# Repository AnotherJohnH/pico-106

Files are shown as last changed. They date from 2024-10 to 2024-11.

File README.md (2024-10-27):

# pico-106

pico-106

Hybrid synthesizer inspired by the Roland Juno-106 (and close relatives).

Some DCOs driven by a Raspberry Pi Pico with a USB MIDI interface.

## Status

Usable as a musical instrument but plenty more to explore...
+ No LFO
+ No PWM, sub-oscillatgor or noise
+ No filter or VCA-envelope on the oscillator signal path

## Hardware

[schematic](https://github.com/AnotherJohnH/pico-106/blob/main/docs/schematic_v0.01.pdf)

... to be improved ;-)

## Software

### Dependencies

+ https://github.com/AnotherJohnH/Platform
+ arm-none-eabi-gcc
+ cmake
+ ninja (make works too)

### Checkout

This repo uses git sub-modules, so checkout using --recurse to clone all the
dependent source...

    git clone --recurse https://github.com/AnotherJohnH/pico-106.git

or

    git clone --recurse ssh://git@github.com/AnotherJohnH/pico-106.git

### Build

Being developed on MacOS but should build on Linux too.

    make

Build directly using cmake...

    mkdir build
    cd build
    cmake -DCMAKE_BUILD_TYPE=Release -DPLT_TARGET=rpipico2 -DCMAKE_TOOLCHAIN_FILE=Platform/MTL/rpipico/toolchain.cmake ..
    make

Flashable image will be found under the build sub directory here...

    .../Source/pico-106.uf2

## License

This project is licensed under the MIT License - see the [LICENSE](LICENSE) file for details

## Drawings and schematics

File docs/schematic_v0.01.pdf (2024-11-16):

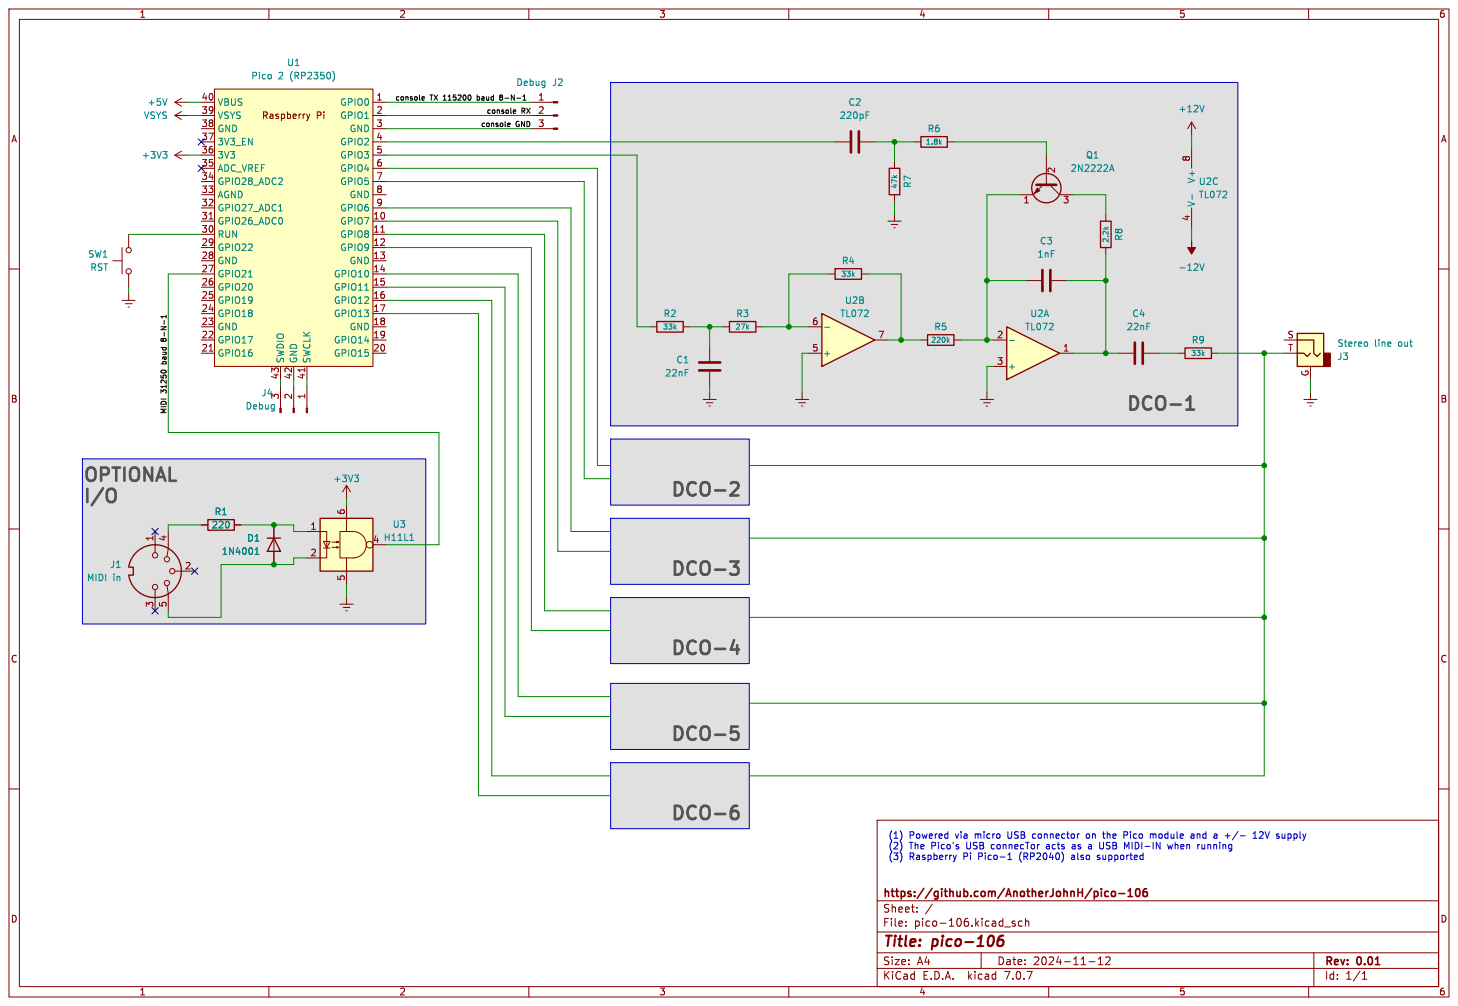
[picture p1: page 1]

5 6 U3 H11L1 Raspberry Pi GPIO0 1 GPIO7 10 GPIO8 11 GPIO9 12 GND 13 GPIO10 14 GPIO11 15 GPIO12 16 GPIO13 17 GND 18 GPIO14 19 GPIO1 2 GPIO15 20 GPIO16 21 GPIO17 22 GND 23 GPIO18 24 GPIO19 25 GPIO20 26 GPIO21 27 GND 28 GPIO22 29 GND 3 RUN 30 GPIO26_ADC0 31 GPIO27_ADC1 32 AGND 33 GPIO28_ADC2 34 ADC_VREF 35

J3Stereo line out MIDI 31250 baud 8-N-1

File: pico-106.kicad_sch Sheet: / https://github.com/AnotherJohnH/pico-106

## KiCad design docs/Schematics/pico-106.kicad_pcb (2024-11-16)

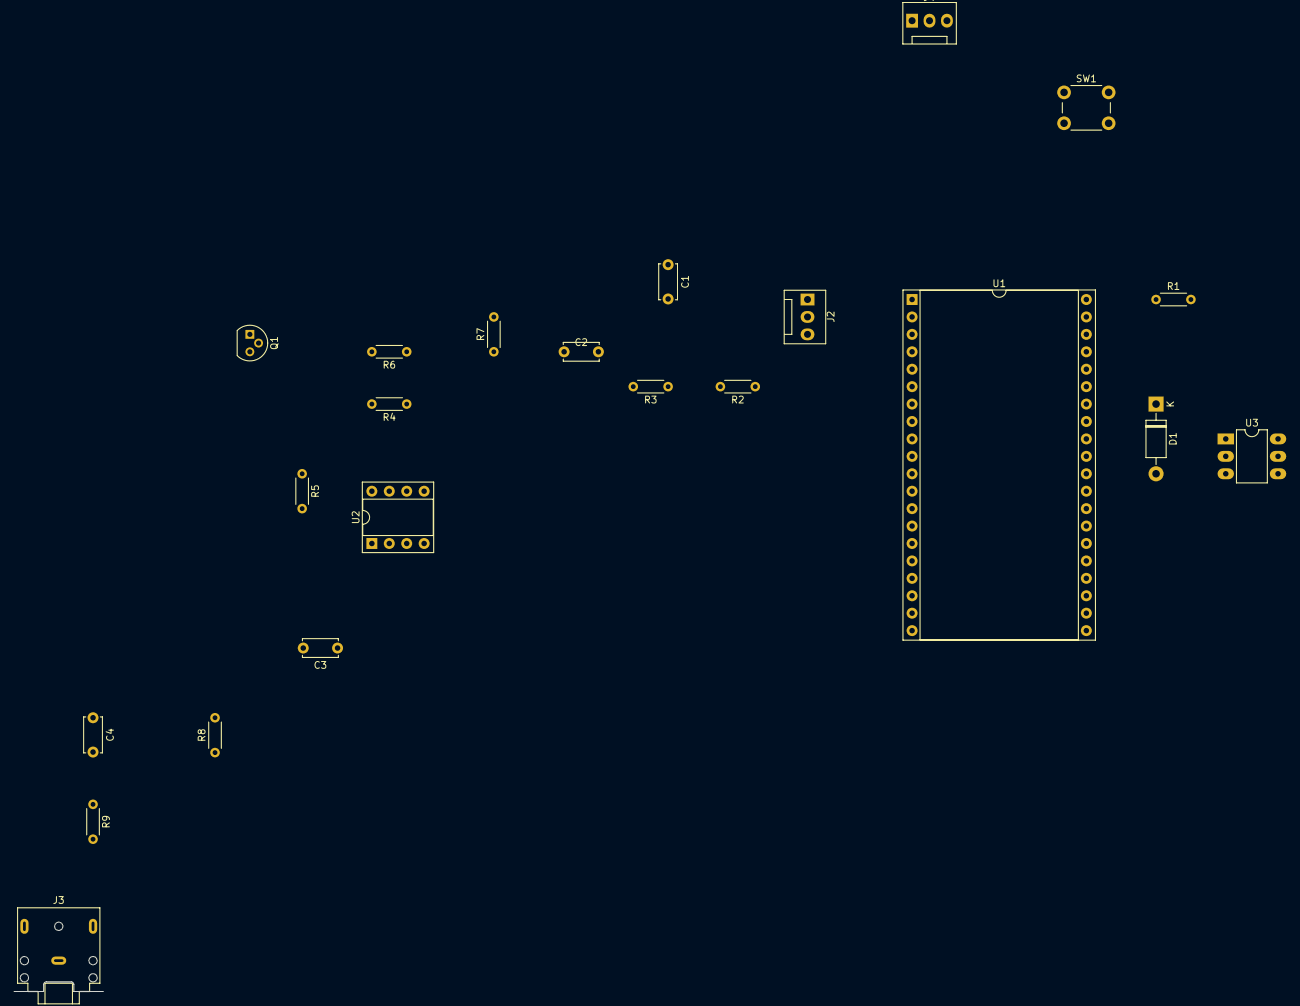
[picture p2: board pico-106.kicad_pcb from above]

Board: 2 copper layers, 22 parts (0 on the bottom side), 22 nets, no tracks yet.

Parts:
C1, C4: 22nF; C_Disc_D5.0mm_W2.5mm_P5.00mm
C2: 220pF; C_Disc_D5.0mm_W2.5mm_P5.00mm
C3: 1nF; C_Disc_D5.0mm_W2.5mm_P5.00mm
D1: 1N4001; D_DO-41_SOD81_P10.16mm_Horizontal
J2, J4: Debug; FanPinHeader_1x03_P2.54mm_Vertical
J3: Stereo line out; Jack_3.5mm_CUI_SJ1-3523N_Horizontal
Q1: 2N2222A; TO-92
R1: 220; R_Axial_DIN0204_L3.6mm_D1.6mm_P5.08mm_Horizontal
R2, R4, R9: 33k; R_Axial_DIN0204_L3.6mm_D1.6mm_P5.08mm_Horizontal
R3: 27k; R_Axial_DIN0204_L3.6mm_D1.6mm_P5.08mm_Horizontal
R5: 220k; R_Axial_DIN0204_L3.6mm_D1.6mm_P5.08mm_Horizontal
R6: 1.8k; R_Axial_DIN0204_L3.6mm_D1.6mm_P5.08mm_Horizontal
R7: 47k; R_Axial_DIN0204_L3.6mm_D1.6mm_P5.08mm_Horizontal
R8: 2.2k; R_Axial_DIN0204_L3.6mm_D1.6mm_P5.08mm_Horizontal
SW1: RST; SW_PUSH_6mm_H5mm
U1: Pico 2 (RP2350); DIP-40_W25.4mm_Socket
U2: TL072; DIP-8_W7.62mm_Socket
U3: H11L1; DIP-6_W7.62mm_LongPads

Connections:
+3V3: U1.36 (3V3), U3.6
+5V: U1.39 (VSYS), U1.40 (VBUS)
/MIDI 31250 baud 8-N-1: U1.27 (GPIO21), U3.4
/console GND: J2.3, U1.3 (GND)
/console RX: J2.2, U1.2 (GPIO1)
/console TX 115200 baud 8-N-1: J2.1, U1.1 (GPIO0)
Earth: C1.1, R7.2, SW1.2, U2.3 (+), U2.5 (+), U3.5
unnamed: C1.2, R2.2, R3.1
unnamed: C2.2, R6.1, R7.1
unnamed: C3.2, C4.1, R8.2, U2.1
unnamed: C4.2, R9.1
unnamed: D1.2 (A), U3.2
unnamed: D1.1 (K), R1.1, U3.1
unnamed: J3.T, R9.2
unnamed: Q1.2 (B), R6.2
unnamed: Q1.3 (C), R8.1
unnamed: C3.1, Q1.1 (E), R5.2, U2.2 (-)
unnamed: R4.2, R5.1, U2.7
unnamed: C2.1, U1.4 (GPIO2)
unnamed: R2.1, U1.5 (GPIO3)
unnamed: SW1.1, U1.30 (RUN)
unnamed: R3.2, R4.1, U2.6 (-)

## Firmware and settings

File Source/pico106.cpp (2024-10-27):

//------------------------------------------------------------------------------
// Copyright (c) 2024 John D. Haughton
//
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
// \brief Synth for Raspberry Pi Pico (based around DCOs like June 106)

#include <cstdio>

#include "STB/MIDIInterface.h"

#include "MTL/MTL.h"
#include "MTL/Digital.h"
#include "MTL/chip/Uart.h"

#include "Synth.h"


// --- Target Hardware Configuration -------------------------------------------

#define HW_MIDI_UART1
#define HW_MIDI_USB_DEVICE
#define HW_LED
#define HW_VOICES   2   // Number of external DCO circuits, max 6


// -----------------------------------------------------------------------------

static Synth<HW_VOICES> synth {};


// --- MIDI-IN -----------------------------------------------------------------

#if defined(HW_MIDI_UART1)

// pico pin 27 : IN

//! Physical MIDI at 31250 baud
class MidiPhys : public MIDI::Interface
{
public:
   MidiPhys(MIDI::Instrument& instrument)
      : MIDI::Interface(instrument)
   {}

   bool empty() const override { return uart.empty(); }

   uint8_t rx() override { return uart.rx(); }

   void tx(uint8_t byte) { return uart.tx(byte); }

private:
   MTL::Uart1_P26_P27 uart{31250, 8, MTL::UART::NONE, 1};
};

static MidiPhys midi_in {synth};

#endif


// --- USB MIDI ----------------------------------------------------------------

#if defined(HW_MIDI_USB_DEVICE)

// pico micro USB : MIDI in

#include "MTL/USBMidiDevice.h"

class MidiUSB : public MIDI::Interface
{
public:
   MidiUSB(MIDI::Instrument& instrument)
      : MIDI::Interface(instrument)
   {}

   bool empty() const override { return device.empty(); }

   uint8_t rx() override { return device.rx(); }

   MTL::USBMidiDevice device{"https://github.com/AnotherJohnH",
                             0x9106, PLT_BCD_VERSION, "pico106",
                             PLT_COMMIT};

   MTL::Usb usb{device};
};

static MidiUSB midi_usb {synth};

extern "C" void IRQ_USBCTRL() { midi_usb.usb.irq(); }

#endif


// --- Key press LED -----------------------------------------------------------

#if defined(HW_LED)

MTL::Digital::Out<MTL::PIN_LED1> led;

#endif


// -----------------------------------------------------------------------------

int MTL_main()
{
   // Clear screen and cursor to home
   printf("\e[2J");
   printf("\e[1,1H");

   printf("\n");
   printf("Program  : pico106\n");
   printf("Author   : Copyright (c) 2024 John D. Haughton\n");
   printf("Version  : %s\n", PLT_VERSION);
   printf("Commit   : %s\n", PLT_COMMIT);
   printf("Built    : %s %s\n", __TIME__, __DATE__);
   printf("Compiler : %s\n", __VERSION__);
   printf("\n");

   while(true)
   {
#if defined(HW_MIDI_UART1)
      midi_in.tick();
#endif

#if defined(HW_MIDI_USB_DEVICE)
      midi_usb.tick();

      midi_usb.setDebug(true);
#endif

#if defined(HW_LED)
      led = synth.isAnyVoiceOn();
#endif
   }

   return 0;
}

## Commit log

2024-10-26 Copy in picoX7 schematic as starting point
    [pico106.kicad_pcb, pico106.kicad_sch]
2024-10-26 Update schematic
    [pico106.kicad_sch]
2024-10-27 Move USB Midi device support into Platform for re-use
    [pico106.kicad_sch]
2024-10-27 Rename project pico-106
    [pico-106.kicad_pcb, pico-106.kicad_sch]
2024-11-09 Add initial spice model
    + also fixed wrong value for C1 on schematic
    [pico-106.kicad_sch]
2024-11-09 Increase DAC frequency (software and hardware change) for better quality waveform
    [pico-106.kicad_sch]
2024-11-16 Capture latest docs
    [pico-106.kicad_pcb, pico-106.kicad_sch]
2025-05-25 Update Plaform to fix I2C and UART drivers on RP2350
